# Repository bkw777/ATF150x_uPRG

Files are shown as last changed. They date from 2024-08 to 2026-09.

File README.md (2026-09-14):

# ATF150x Programmers based on FT232H modules

ATF150x programmer in the form of a "hat" PCB for common FT232H USB modules like CJMCU-232H or Adafruit 2264.

Includes a 12V supply for VPP on /OE1 to recover CPLDs that have JTAG disabled.

There are 2 versions. Both versions provide:  
* FT232H
* 10-pin JTAG port with ATMEL/ALtera JTAG-A pinout
* 12V power supply for VPP
* Optional 12V VPP out on JTAG pin 6
* JTAG VCC switchable:
  * programmer supplies 3V3 VCC to target
  * programmer supplies 5V VCC to target
  * target supplies own VCC

----

## Adafruit 2264  
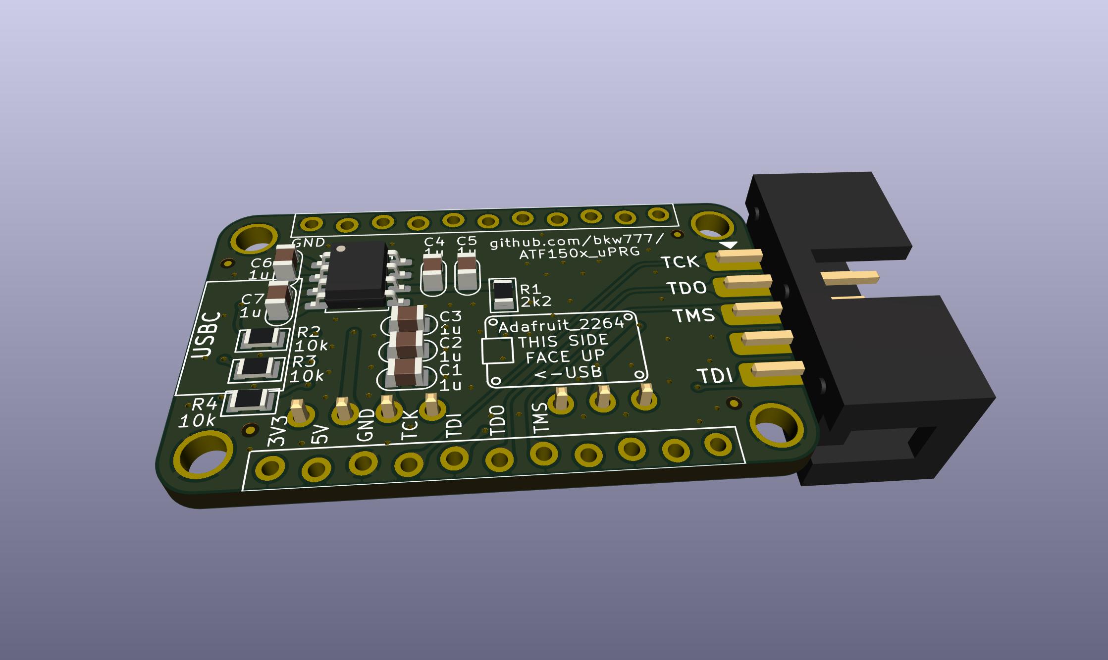
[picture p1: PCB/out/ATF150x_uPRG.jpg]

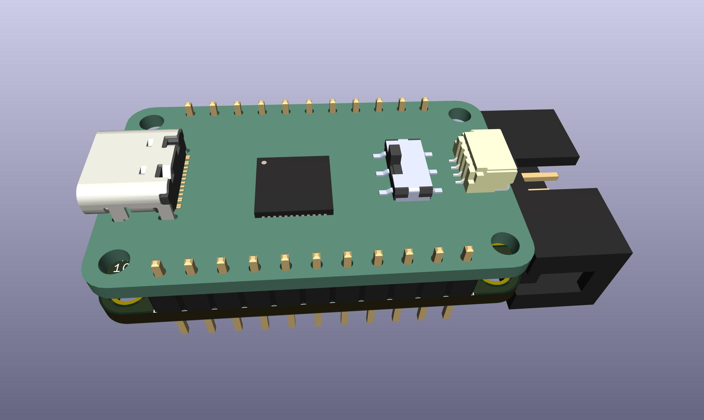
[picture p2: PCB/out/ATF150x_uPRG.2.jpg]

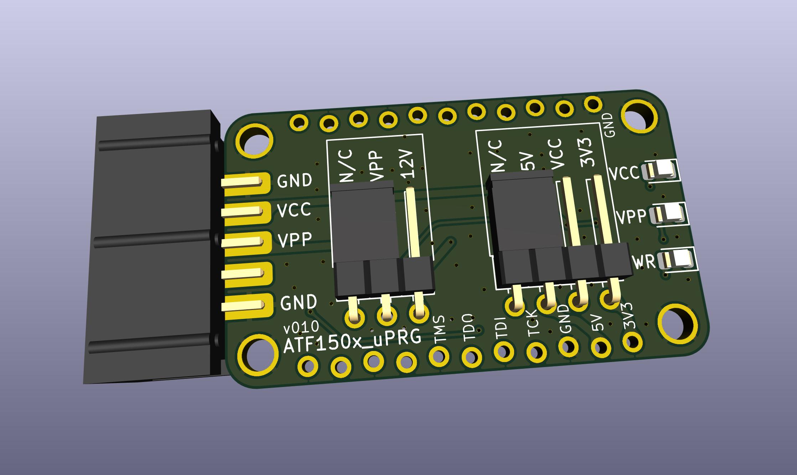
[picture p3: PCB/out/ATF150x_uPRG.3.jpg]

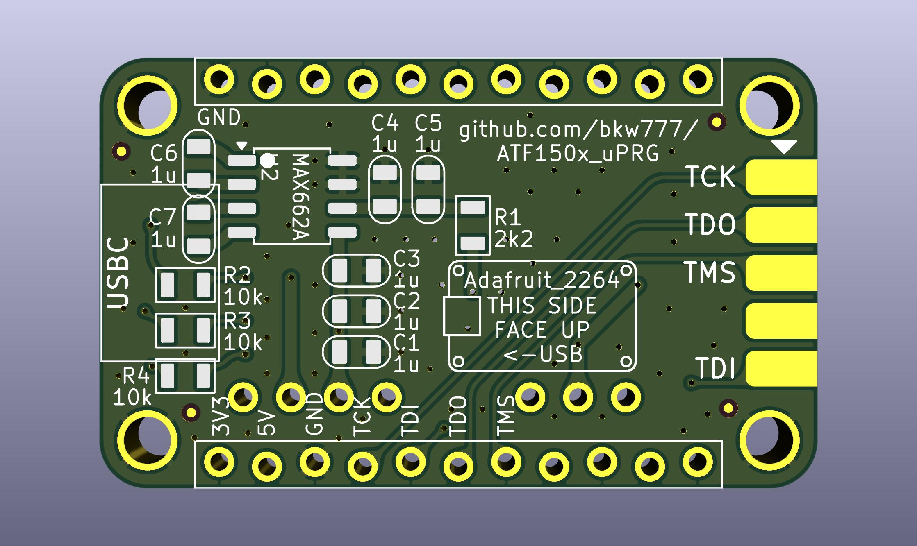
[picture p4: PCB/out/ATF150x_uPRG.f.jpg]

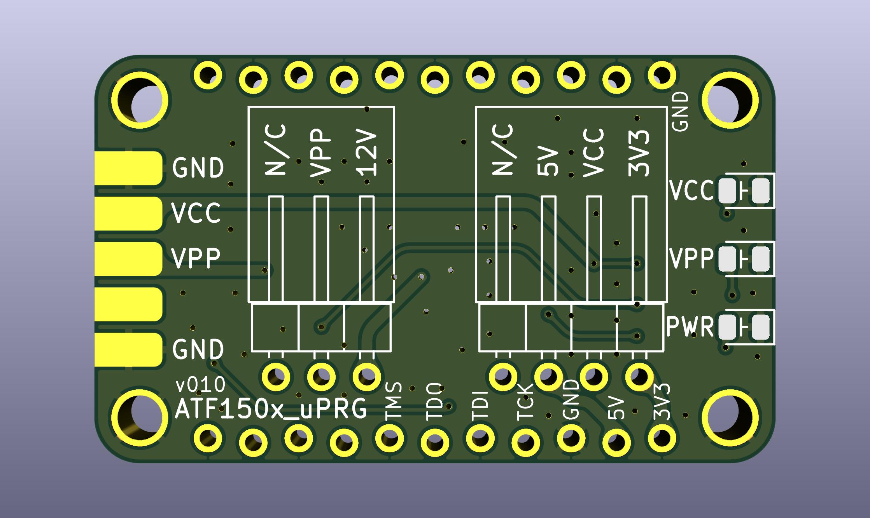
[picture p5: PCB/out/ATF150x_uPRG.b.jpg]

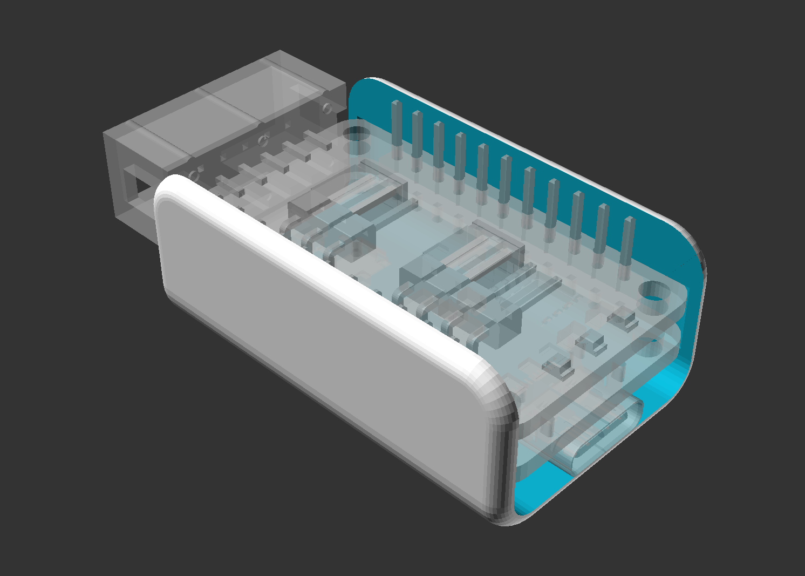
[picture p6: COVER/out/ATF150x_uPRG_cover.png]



[v010 PCB at OSHPark](https://oshpark.com/shared_projects/TQWUH0NG)  
[BOM @ DigiKey](https://www.digikey.com/short/crp904w2)  
(includes the Adafruit 2264 and 2 types of JTAG cable)
<!-- _sw version with slide switches and 33 ohms on the jtag lines
https://www.digikey.com/short/nvr0cz3h
-->
Cover [ATF150x_uPRG.stl](COVER/out/ATF150x_uPRG_cover.stl)

----

## CJMCU-232H  
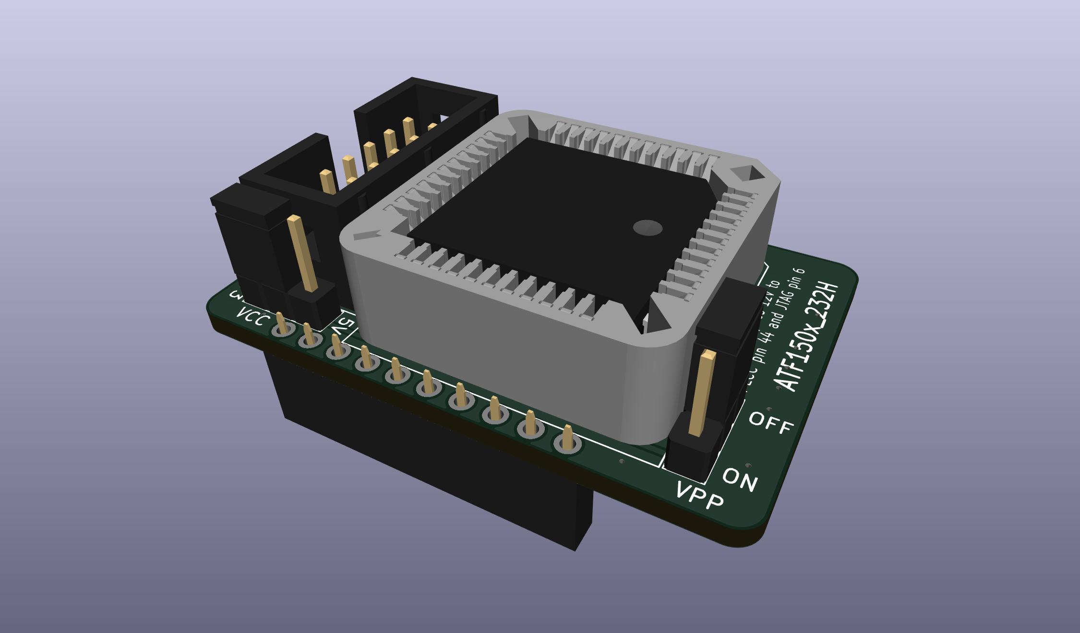
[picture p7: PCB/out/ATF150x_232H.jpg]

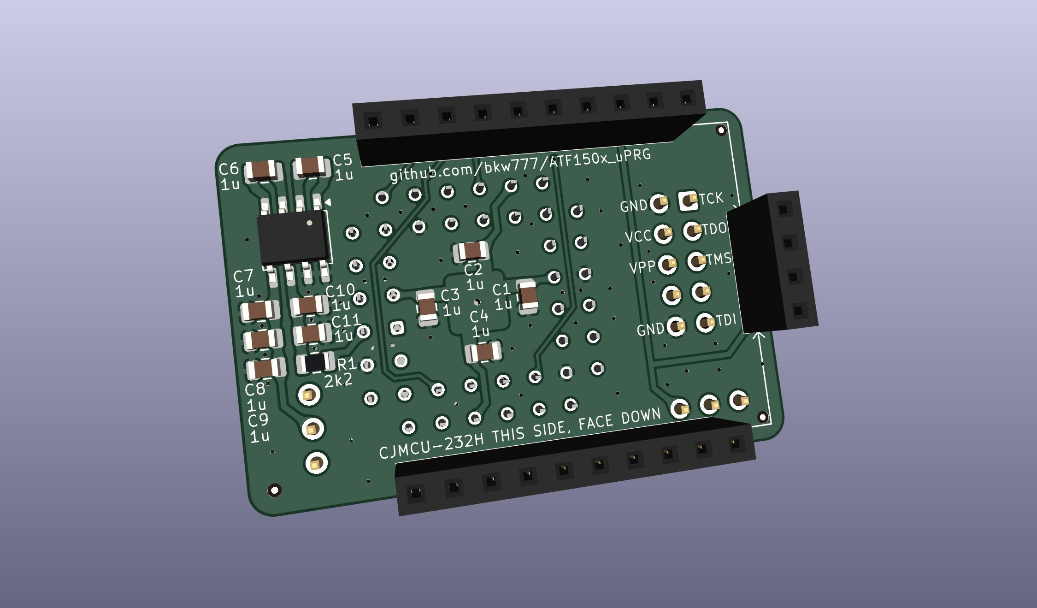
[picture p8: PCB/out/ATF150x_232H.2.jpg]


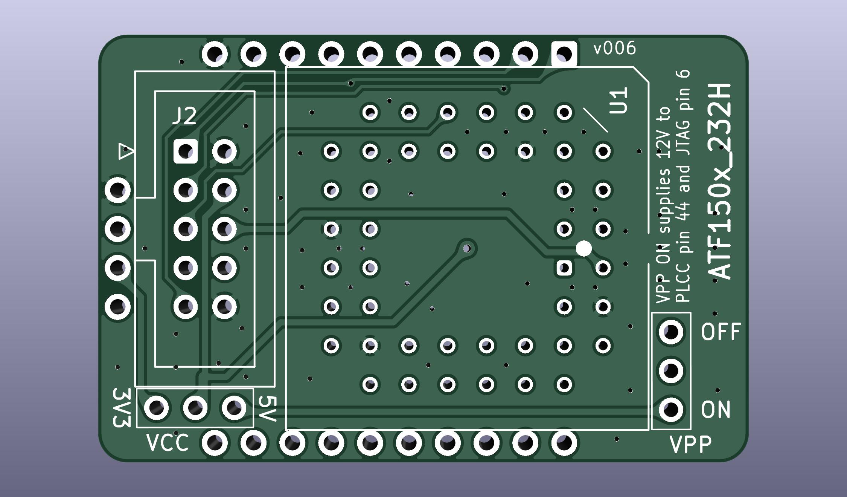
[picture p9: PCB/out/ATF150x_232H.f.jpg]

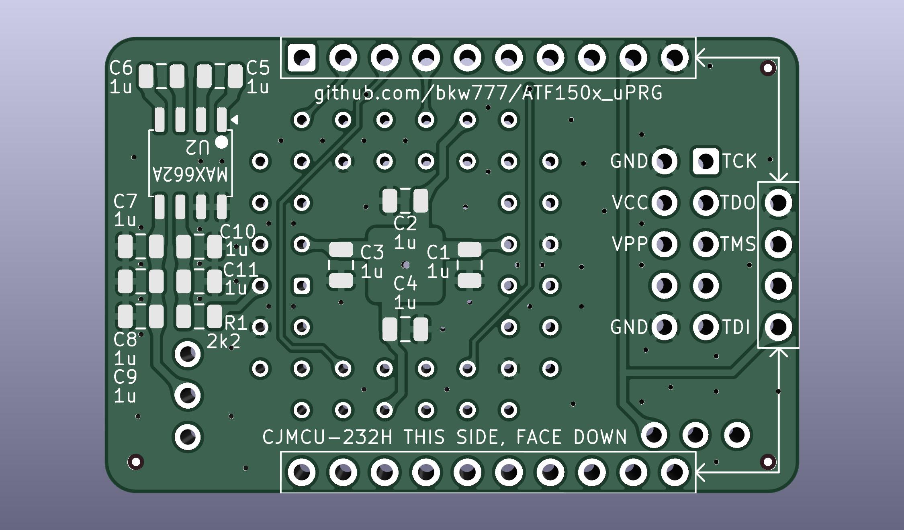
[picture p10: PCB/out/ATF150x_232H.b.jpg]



----

## VPP-over-JTAG
When the VPP jumper or switch is ON, 12V is supplied to JTAG pin 6 (and PLCC pin 44 on the CJMU-232H)  
This forces the ATF150x to enable it's JTAG pins even if the current gateware disabled JTAG to use those pins for GPIO.  
VPP does NOT overcome the secure programming flag.  

[ATF150x_uDEV](https://github.com/bkw777/ATF150x_uDEV) includes a matching option to receive VPP on JTAG pin 6.
  
JTAG pin 6 should be N/C on most Altera JTAG-A targets, so it should be safe even for other devices, but 12V is 12V, so **Don't enable VPP with an unknown device connected to JTAG**  

# Credits
Modified from [hackup.net ATF1504-FT232HQ Shield](https://www.hackup.net/2020/01/erasing-and-programming-the-atf1504-cpld/)

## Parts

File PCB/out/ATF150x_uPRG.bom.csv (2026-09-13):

Reference | Value | Datasheet | Footprint | Qty | DNP | MPN
C1,C2,C3,C4,C5,C6,C7 | 1u | ~ | 000_LOCAL:C_0805 | 7 |  | GMC21X7R105K50NT
J2 | Altera JTAG-A+VPP | datasheets/JTAG-A.pdf | 000_LOCAL:IDC-Header_2x05_P2.54mm pcb-edge | 1 |  | 302-S101
JP1 | VCC | ~ | 000_LOCAL:PinHeader_1x04_P2.54mm_Horizontal | 1 |  | PRPC004SBAN-M71RC
JP2 | VPP | ~ | 000_LOCAL:PinHeader_1x03_P2.54mm_Horizontal | 1 |  | PRPC003SBAN-M71RC
LED1 | AMBER | datasheets/B1701.pdf | 000_LOCAL:LED_0805 | 1 |  | B1701UY--20D000214U1930
LED2 | RED | datasheets/B1701.pdf | 000_LOCAL:LED_0805 | 1 |  | B1701USD-20D000114U1930
LED3 | GREEN | datasheets/B1701.pdf | 000_LOCAL:LED_0805 | 1 |  | B1701NG--20D000314U1930
R1 | 2k2 | ~ | 000_LOCAL:R_0805 | 1 |  | ERJ-6GEYJ222V
R2,R3,R4 | 10k | datasheets/AOA0000C301.pdf | 000_LOCAL:R_0805 | 3 |  | ERJ-6GEYJ103V
U2 | MAX662A | datasheets/MAX662A.pdf | 000_LOCAL:SOIC-8 | 1 |  | MAX662ACSA

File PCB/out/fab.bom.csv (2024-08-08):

Reference | Value | Datasheet | Footprint | Qty | DNP | MPN
C1,C2,C3,C4,C5,C6,C7 | 1u | ~ | 000_LOCAL:C_0805 | 7 |  | CL21B105KBFNNNG
J2 | Altera JTAG-A+VPP | datasheets/JTAG-A.pdf | 000_LOCAL:IDC-Header_2x05_P2.54mm pcb-edge | 1 |  | 302-S101
LED1 | GREEN | datasheets/B1701.pdf | 000_LOCAL:LED_0805 | 1 |  | B1701NG--20D000314U1930
LED2 | AMBER | datasheets/B1701.pdf | 000_LOCAL:LED_0805 | 1 |  | B1701UY--20D000214U1930
LED3 | RED | datasheets/B1701.pdf | 000_LOCAL:LED_0805 | 1 |  | B1701USD-20D000114U1930
R1 | 2k2 | ~ | 000_LOCAL:R_0805 | 1 |  | ERJ-6GEYJ222V
R2,R3,R4 | 10k | ~ | 000_LOCAL:R_0805 | 3 |  | ERJ-6GEYJ103V
R5,R6,R7,R8 | 33 | ~ | 000_LOCAL:R_0805 | 4 |  | ERJ-6GEYJ330V
SW1 | SP3T | datasheets/cus.pdf | 000_LOCAL:CUS-13B pth | 1 |  | CUS-13TB
SW2 | SPDT | datasheets/cus.pdf | 000_LOCAL:CUS-12B pth | 1 |  | CUS-12TB
U1 | MAX662A | datasheets/MAX662A.pdf | 000_LOCAL:SOIC-8 | 1 |  | MAX662ACSA+T

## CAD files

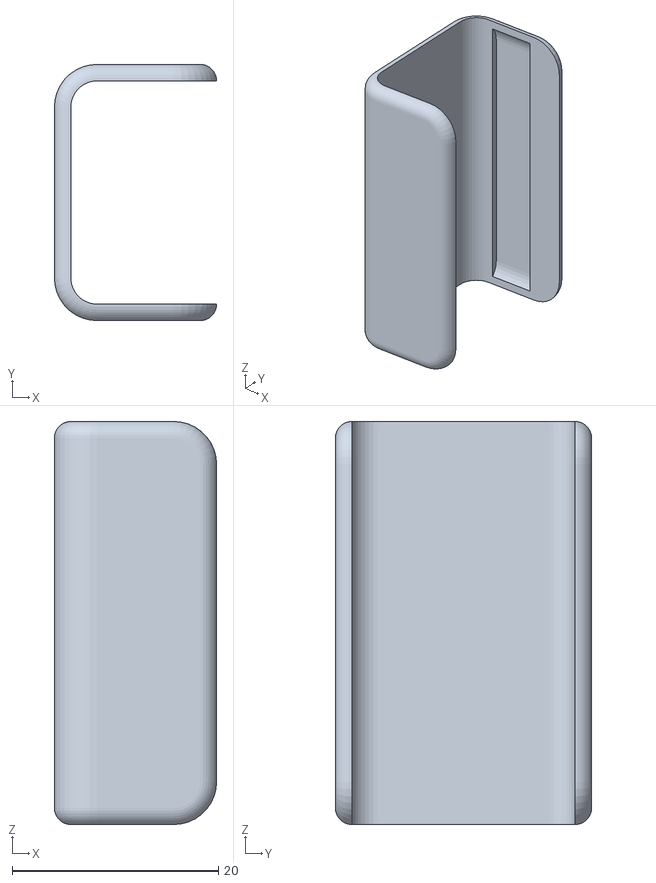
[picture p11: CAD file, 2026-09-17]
COVER/out/ATF150x_uPRG_cover.stl
15.7 x 24.9 x 39.1

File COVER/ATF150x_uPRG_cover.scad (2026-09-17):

/*
   Cover for ATF150x_uPRG
   Brian K. White - b.kenyon.w@gmail.com
   https://github.com/bkw777/ATF150x_uPRG
*/

pcb_stl = "lib/PCB.stl";

$fn = 36;              // arc smoothness
in = 25.4;
mil = in/1000;

wall_thickness = 1.6;
wt = wall_thickness;
min_wall_thickness = 0.8;
fitment_clearance = 0.2;
fc = fitment_clearance;

pcb_w = 1500*mil;      // pcb long dim
pcb_d = 900*mil;       // pcb short dim
pcb_h = 1.6;           // pcb thickness
pcb_r = 100*mil;       // pcb corner radius

insulator_h = 100*mil; // pin header insulator height

interior_major_radius = 100*mil;

pcb_stack = pcb_h + insulator_h + pcb_h;

bottom_components_height = 3.2;

top_components_height = 5;
th = top_components_height;

// bottom interior height
bih = pcb_stack + bottom_components_height;

// bottom exterior height
beh = bih + fc + wt;

ew = pcb_w+1;        // exterior width
ed = pcb_d + fc*2 + min_wall_thickness*2; // exterior depth
eh = th + beh;       // exterior height
ir = interior_major_radius; // interior radius
ra = ir+wt;          // major radius
rb = wt;             // minor radius

// =============================================================

include <lib/handy.scad>;

module pcb() {
  rotate([180,0,0]) %import(pcb_stl);
}

module simple_cover () {

  difference() {
  
    // add
    hull() {
      // top
      difference() {
        mirror_copy([0,1,0])
          translate([0,ed/2-wt,-ra+th])
            rotate([90,0,0])
              rcube([ew,ra*2,wt*2],rh=ra,rv=rb,t=0);
        // cut bottom half off
        translate([0,0,-eh/2+th-ra])
          cube([ew+2,ed+2,eh],center=true);
      }

      // bottom
      difference(){
        mirror_copy([1,0,0])
          translate([ew/2-wt,0,ra-beh])
            rotate([0,90,0])
              rcube([ra*2,ed,wt*2],rh=ra,rv=rb,t=0);
        // cut top half off
        translate([0,0,eh/2-beh+ra])
          cube([ew+2,ed+2,eh],center=true);        
      }
    }
  
    // remove
    group() {
      // main
      ch = eh+1;
      translate([0,0,ch/2-beh+wt])
        rotate([0,90,0]) rcube([ch,ed-wt*2,ew+2],rh=ir);

      // pcb slot
      translate([0,0,-pcb_stack/2])
        rcube([pcb_w+fc*2,pcb_d+fc*2,pcb_stack+fc*2],rh=pcb_r+fc);
    
    }
  
  }

}

// =============================================================

pcb();

    pr = ($preview) ? 0 : 90;
    pz = ($preview) ? 0 : ew/2;
    px = ($preview) ? 0 : beh-eh/2;    
    translate ([px,0,pz])
      rotate([0,pr,0])
        simple_cover();

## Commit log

2024-06-24 Re-draw everything, add /OE1 to JTAG, all caps same 1u
    [ATF2FT232HQ.kicad_pcb, ATF2FT232HQ.sch, Adafruit_2264.step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]
2024-06-24 fix filenames, H_ looks like L in tiny blurry silkscreen
    [FT232H-ATF150x.kicad_pcb, FT232H-ATF150x.kicad_sch]
2024-06-24 comments & silkscreen
    [FT232H-ATF150x.kicad_pcb, FT232H-ATF150x.kicad_sch]
2024-06-24 jtag signal directions
    [FT232H-ATF150x.kicad_sch]
2024-06-25 reposition everything so jtag doesn't cover the FT232H module pins
    [FT232H-ATF150x.kicad_pcb]
2024-07-02 add ATF150x_uPRG
    [ATF150x_uPRG.kicad_pcb, ATF150x_uPRG.kicad_sch, ATF150x_uPRG_s.kicad_pcb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]
2024-07-04 cjmcu board use max662 shutdown pin
    [ATF150x_232H.kicad_pcb, ATF150x_232H.kicad_sch]
2024-07-04 adafruit board use max662 shutdown pin
    [ATF150x_uPRG.kicad_pcb, ATF150x_uPRG.kicad_sch, ATF150x_uPRG_j.kicad_pcb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]
2024-07-14 cjmcu minor trace moves
    [ATF150x_232H.kicad_pcb]
2024-07-19 switch power to max662 instead of using shutdown pin so vpp actually shuts off
    [ATF150x_232H.kicad_pcb, ATF150x_232H.kicad_sch, ATF150x_uPRG.kicad_pcb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]
2024-08-08 fab exports, bom, centroid
    [ATF150x_uPRG.BOM.csv, ATF150x_uPRG.kicad_pcb, ATF150x_uPRG.kicad_sch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]
2024-08-08 add squid cable to bom
    [ATF150x_uPRG.BOM.csv]
2026-09-06 make the jumper version the main version
    [ATF150x_uPRG.kicad_pcb, ATF150x_uPRG.kicad_sch, ATF150x_uPRG_j.kicad_pcb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]
2026-09-07 _sw fillet tracks
    [ATF150x_uPRG_sw.kicad_pcb, ATF150x_uPRG_sw.kicad_sch]
2026-09-13 simplify, replace slide switches with jumpers, remove 33ohms
    [ATF150x_uPRG.BOM.csv, ATF150x_uPRG.bom.csv, ATF150x_uPRG.kicad_pcb]
2026-09-13 sch add mpns & pcba bom, update digikey fuller bom
    [ATF150x_uPRG.bom.csv, ATF150x_uPRG.kicad_sch]
2026-09-17 silkscreen, cover
    [ATF150x_uPRG.kicad_pcb, ATF150x_uPRG_cover.scad, ATF150x_uPRG_cover.stl]
2026-09-30 silkscreen & minor trace move
    [ATF150x_uPRG.kicad_pcb]
